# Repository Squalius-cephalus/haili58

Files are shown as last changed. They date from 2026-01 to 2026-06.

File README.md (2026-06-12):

# Haili58

Haili58 is a nrf52840 based 58-key column staggered split keyboard. PCB uses hotswap sockets. Design is inspired from REVIUNG41 and Corne keyboards.

PCB is designed for MX and Gateron low profile key switches. The keyboard is designed to be used with a USB dongle.

haili58 GLP and MX variant

## [Build Guide](https://github.com/Squalius-cephalus/haili58/wiki/Build-Guide)

## Firmware
Haili58 uses [ZMK firmware.](https://github.com/Squalius-cephalus/haili58_zmk)

TODO:
- RMK Firmware

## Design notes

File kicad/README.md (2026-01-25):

## Kicad Footprints

This project uses footprints from various repositories

 - [OLED Display 128x32](https://github.com/crides/kleeb/tree/master/display.pretty)
 - [Diode THT/SMD](https://github.com/foostan/kbd) 
 - [Power Switch MSK12C02](https://github.com/joe-scotto/scottokeebs/tree/main/Extras/ScottoKicad)
 - [nice!nano V2](https://github.com/joe-scotto/scottokeebs/tree/main/Extras/ScottoKicad)
 - [GLP Hotswap Socket](https://github.com/siderakb/key-switches.pretty)

Few of the footprints has been edited, those can be found in the **haili_project.pretty** directory.

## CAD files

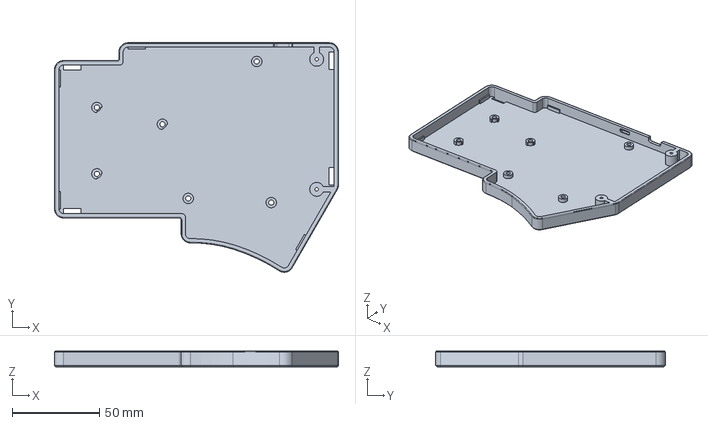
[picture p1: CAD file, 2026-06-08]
case/case_rev2/GLP/case.step
162.9 x 131.7 x 9.00 mm

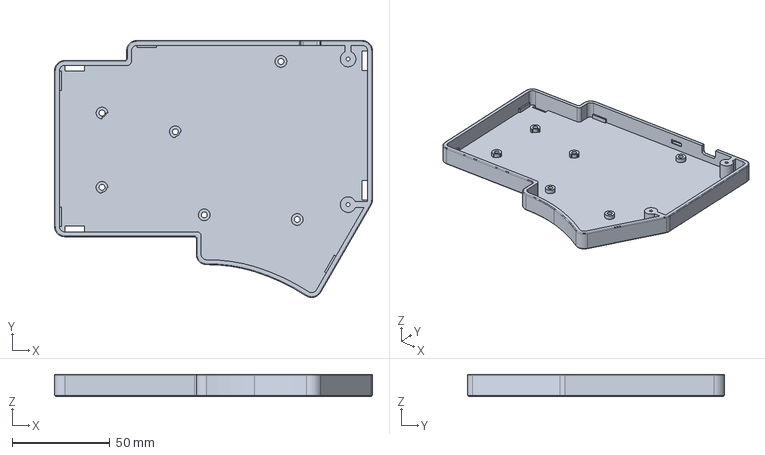
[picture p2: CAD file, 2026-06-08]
case/case_rev2/MX/case.step
162.9 x 131.7 x 11.5 mm

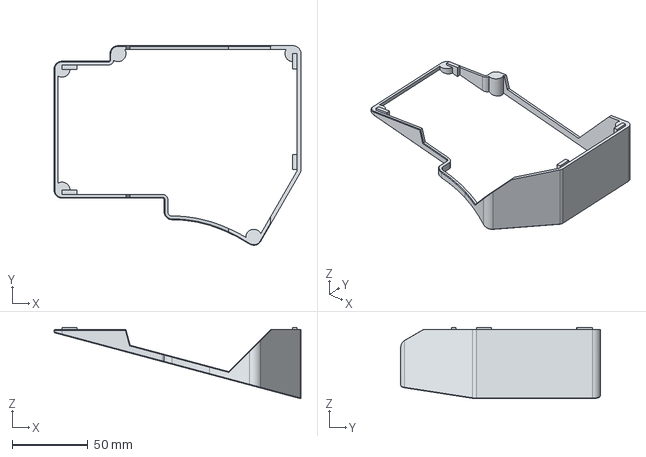
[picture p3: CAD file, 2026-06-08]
case/case_rev2/Tenting/15deg.step
162.9 x 131.7 x 47.0 mm

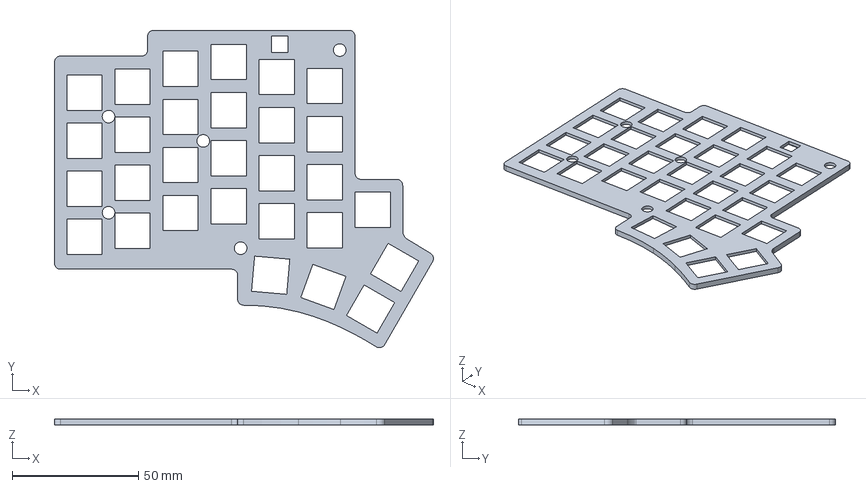
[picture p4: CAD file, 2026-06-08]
case/case_rev2/GLP/plate.step
150.3 x 125.9 x 2.50 mm

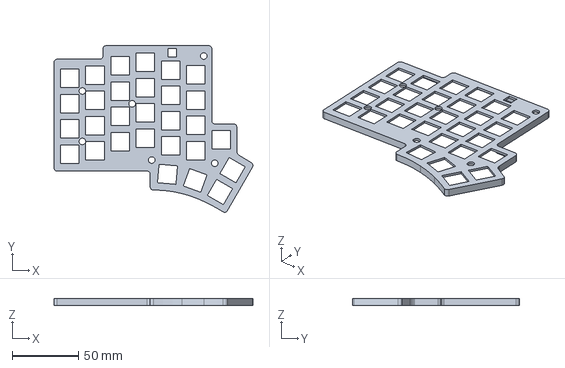
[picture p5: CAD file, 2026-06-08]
case/case_rev2/MX/plate.step
150.3 x 125.9 x 5.00 mm

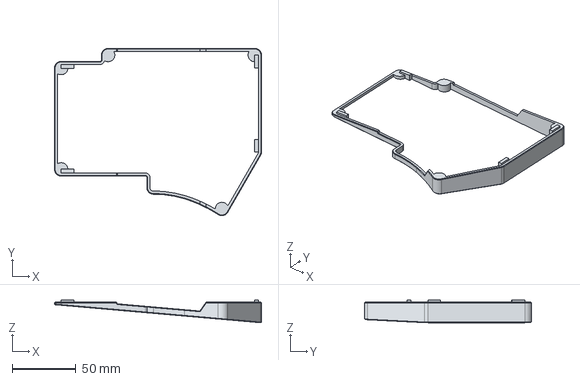
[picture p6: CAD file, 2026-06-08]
case/case_rev2/Tenting/5deg.step
162.9 x 131.7 x 17.7 mm

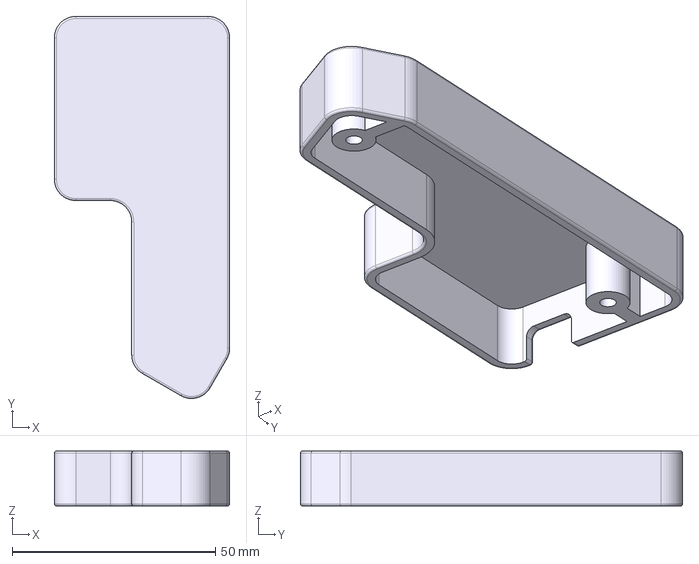
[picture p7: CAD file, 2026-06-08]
case/case_rev2/GLP/battery_cover.step
43.2 x 94.0 x 13.5 mm

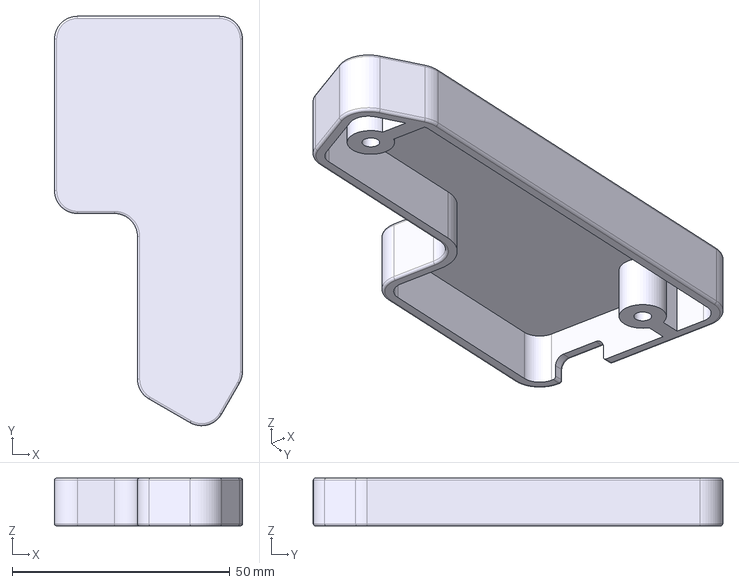
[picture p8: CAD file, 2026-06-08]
case/case_rev2/MX/battery_cover.step
43.2 x 94.0 x 11.0 mm

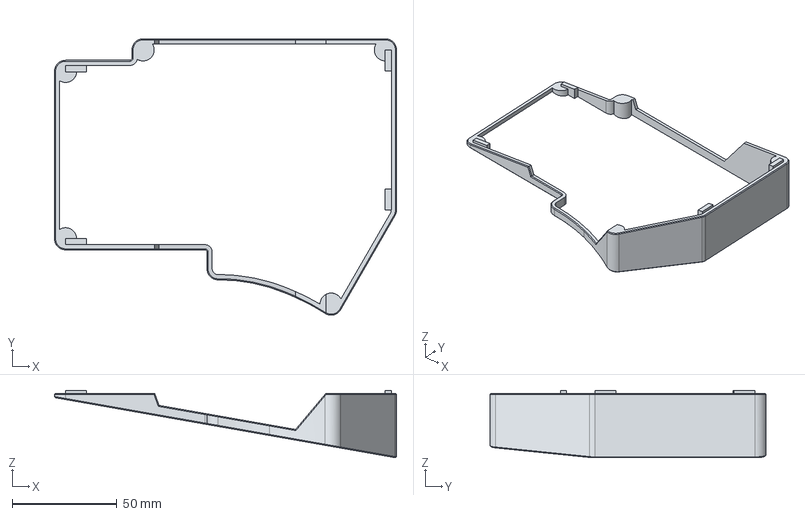
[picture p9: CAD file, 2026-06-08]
case/case_rev2/Tenting/10deg.step
162.9 x 131.7 x 32.1 mm

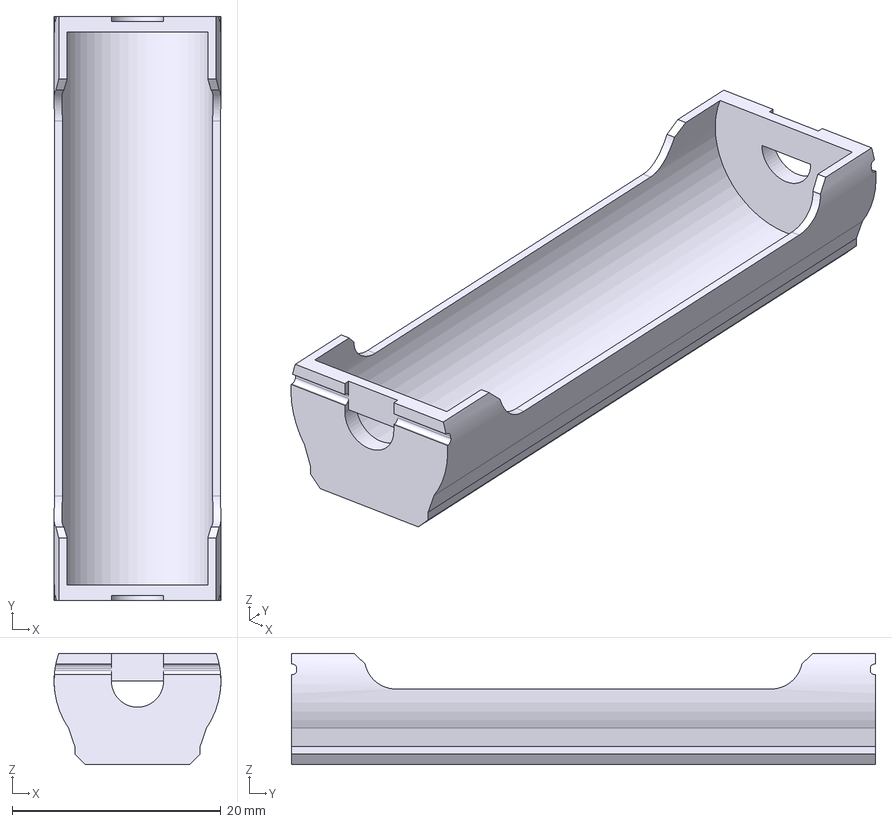
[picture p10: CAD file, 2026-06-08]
case/battery_holder/14500_holder.step
16.0 x 56.0 x 10.6 mm

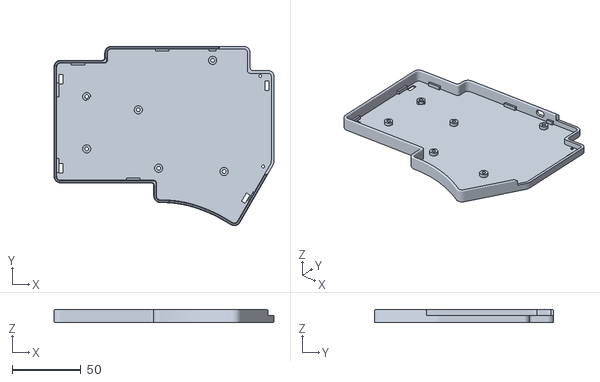
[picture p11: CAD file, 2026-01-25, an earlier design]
case/case_rev1/GLP/Body.stl
160.2 x 130.7 x 9.40

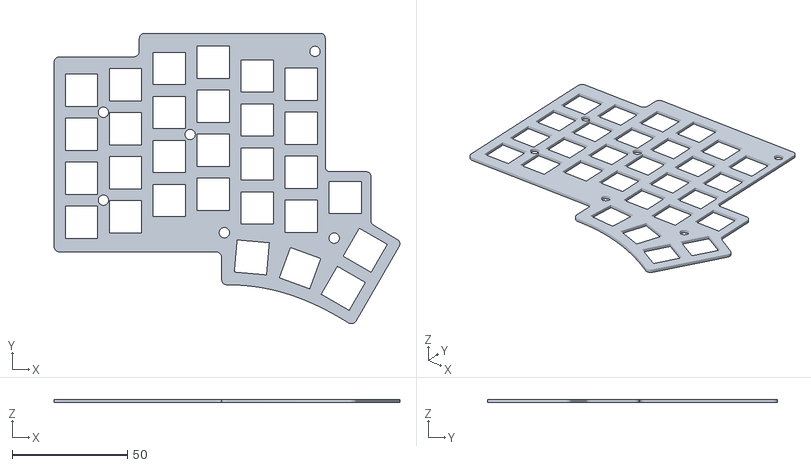
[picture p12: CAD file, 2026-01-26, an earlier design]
case/case_rev1/MX/Plate_without_reset.stl
149.9 x 125.9 x 1.50

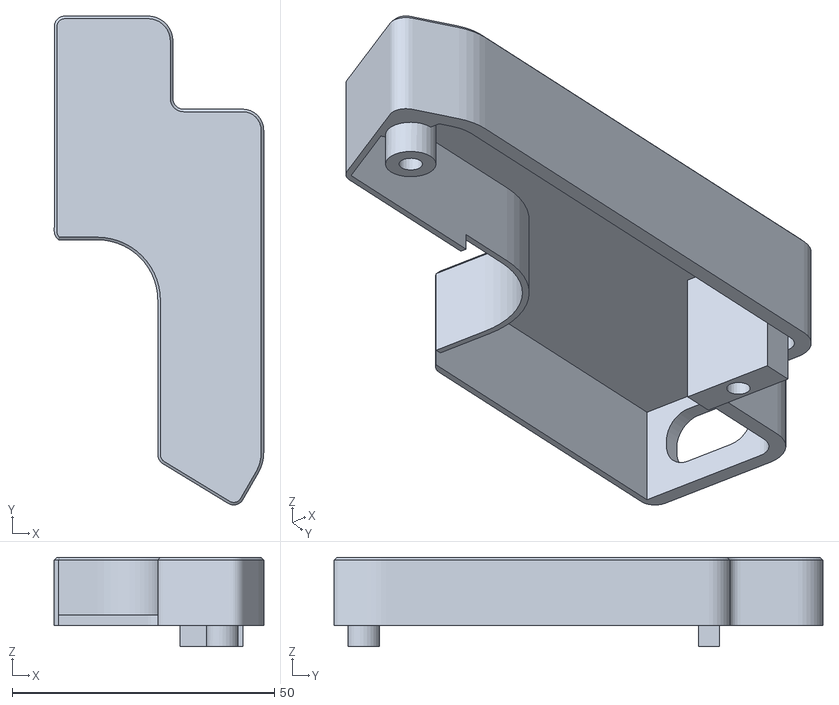
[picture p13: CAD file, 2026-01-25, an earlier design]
case/case_rev1/GLP/Cover.stl
39.9 x 93.2 x 17.0

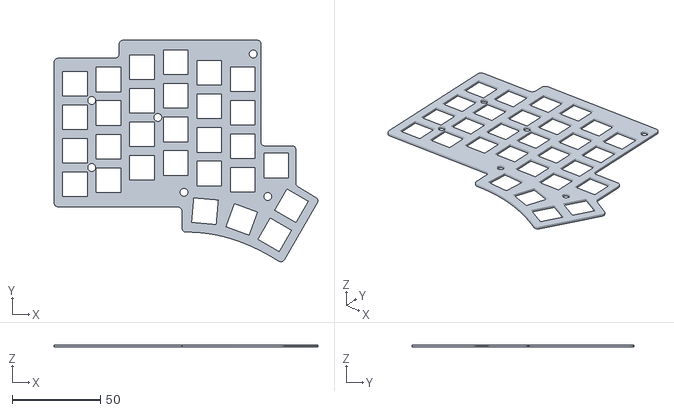
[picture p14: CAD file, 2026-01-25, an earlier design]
case/case_rev1/GLP/Plate_without_reset.stl
149.9 x 125.9 x 1.40

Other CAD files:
case/case_rev1/MX/Plate.stl
case/case_rev1/MX/Body.stl
case/case_rev1/GLP/Plate.stl

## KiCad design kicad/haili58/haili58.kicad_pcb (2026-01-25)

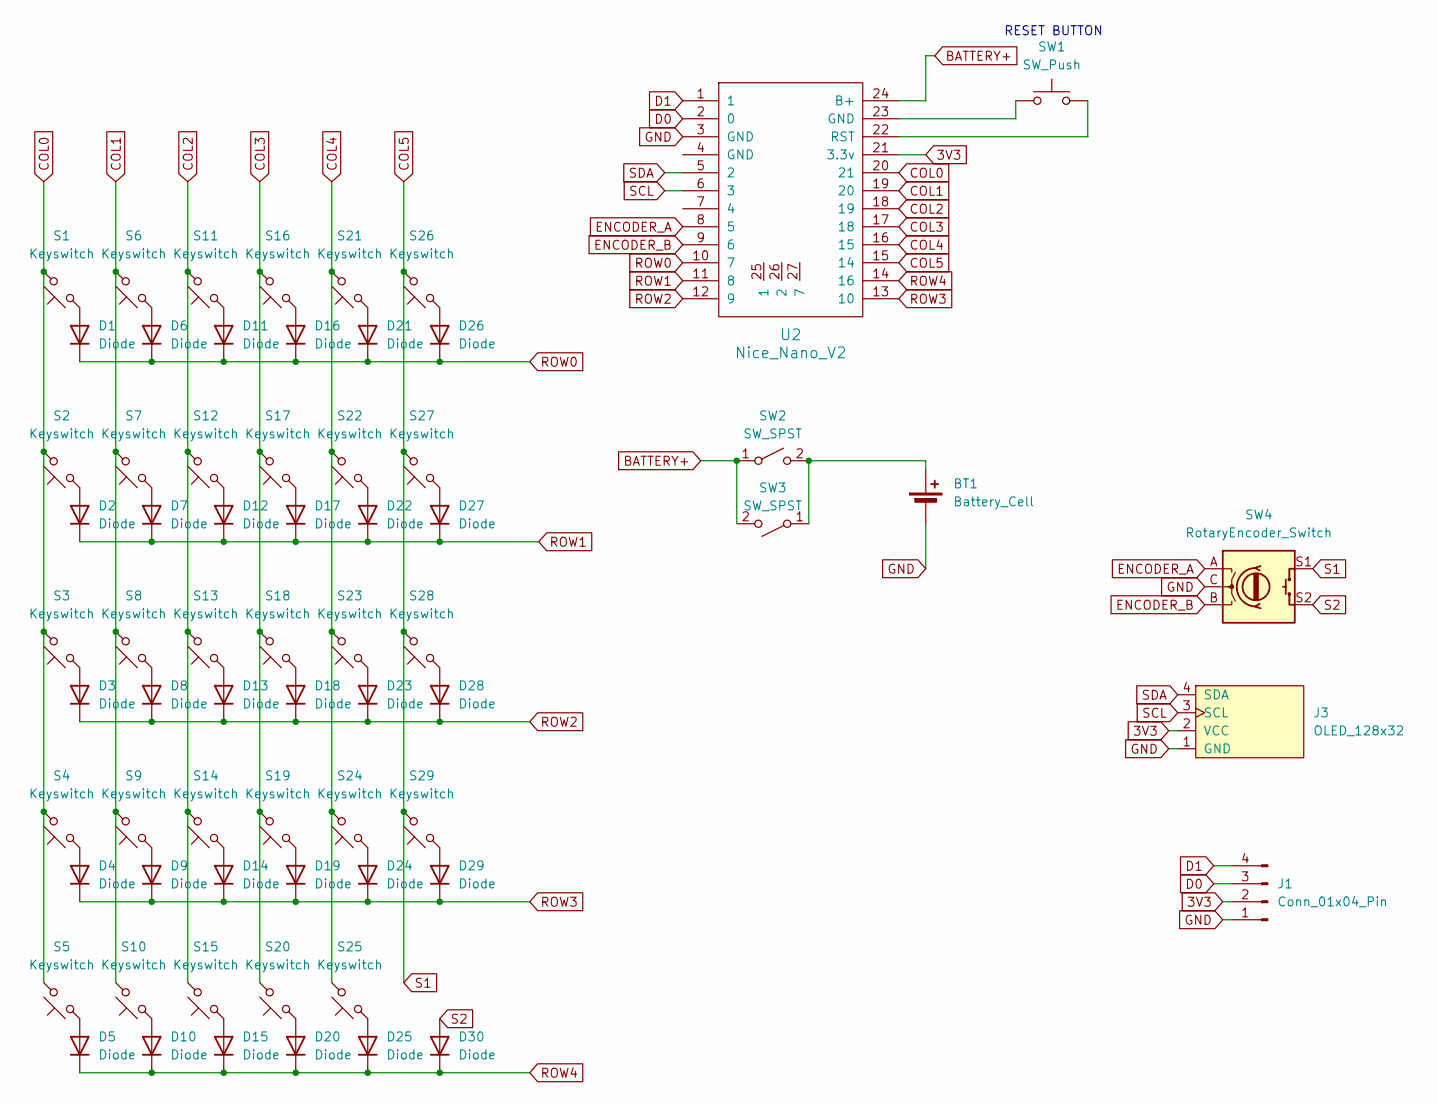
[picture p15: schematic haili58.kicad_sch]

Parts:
BT1: Battery_Cell; Battery_Pins_2mm
D1, D2, D3, D4, D5, D6, D7, D8, D9, D10, D11, D12, D13, D14, D15, D16, D17, D18, D19, D20, D21, D22, D23, D24, D25, D26, D27, D28, D29, D30: Diode; D3_TH_SMD_v2
J1: Conn_01x04_Pin; PinSocket_1x04_P2.54mm_Vertical
J3: OLED_128x32; OLED-128x32-double-sided
S1, S2, S3, S4, S5, S6, S7, S8, S9, S10, S11, S12, S13, S14, S15, S16, S17, S18, S19, S20, S21, S22, S23, S24, S25, S26, S27, S28, S29: Keyswitch; SW_Gateron_LowProfile_HotSwap_PTH_edited
SW1: SW_Push; SW_PUSH_6mm_H4.3mm
SW2, SW3: SW_SPST; Switch_MSK12C02
SW4: RotaryEncoder_Switch; RotaryEncoder_Alps_EC11E-Switch_Vertical_H20mm
U2: Nice_Nano_V2; Nice_Nano_V2_edited

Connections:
3V3: J1.2, J3.2 (VCC), U2.21 (3.3v)
BATTERY+: SW2.1 (A), SW3.2 (B), U2.24 (B+)
COL0: S1.2, S2.2, S3.2, S4.2, S5.2, U2.20 (21)
COL1: S6.2, S7.2, S8.2, S9.2, S10.2, U2.19 (20)
COL2: S11.2, S12.2, S13.2, S14.2, S15.2, U2.18 (19)
COL3: S16.2, S17.2, S18.2, S19.2, S20.2, U2.17 (18)
COL4: S21.2, S22.2, S23.2, S24.2, S25.2, U2.16 (15)
COL5: S26.2, S27.2, S28.2, S29.2, SW4.S1, U2.15 (14)
D0: J1.3, U2.2 (0)
D1: J1.4, U2.1
ENCODER_A: SW4.A, U2.8 (5)
ENCODER_B: SW4.B, U2.9 (6)
GND: BT1.2 (-), J1.1, J3.1 (GND), SW4.C, U2.3 (GND)
unnamed: BT1.1 (+), SW2.2 (B), SW3.1 (A)
unnamed: D1.2 (A), S1.1
unnamed: D2.2 (A), S2.1
unnamed: D3.2 (A), S3.1
unnamed: D4.2 (A), S4.1
unnamed: D5.2 (A), S5.1
unnamed: D6.2 (A), S6.1
unnamed: D7.2 (A), S7.1
unnamed: D8.2 (A), S8.1
unnamed: D9.2 (A), S9.1
unnamed: D10.2 (A), S10.1
unnamed: D11.2 (A), S11.1
unnamed: D12.2 (A), S12.1
unnamed: D13.2 (A), S13.1
unnamed: D14.2 (A), S14.1
unnamed: D15.2 (A), S15.1
unnamed: D16.2 (A), S16.1
unnamed: D17.2 (A), S17.1
unnamed: D18.2 (A), S18.1
unnamed: D19.2 (A), S19.1
unnamed: D20.2 (A), S20.1
unnamed: D21.2 (A), S21.1
unnamed: D22.2 (A), S22.1
unnamed: D23.2 (A), S23.1
unnamed: D24.2 (A), S24.1
unnamed: D25.2 (A), S25.1
unnamed: D26.2 (A), S26.1
unnamed: D27.2 (A), S27.1
unnamed: D28.2 (A), S28.1
unnamed: D29.2 (A), S29.1
unnamed: SW1.1, U2.23 (GND)
unnamed: SW1.2, U2.22 (RST)
ROW0: D1.1 (K), D6.1 (K), D11.1 (K), D16.1 (K), D21.1 (K), D26.1 (K), U2.10 (7)
ROW1: D2.1 (K), D7.1 (K), D12.1 (K), D17.1 (K), D22.1 (K), D27.1 (K), U2.11 (8)
ROW2: D3.1 (K), D8.1 (K), D13.1 (K), D18.1 (K), D23.1 (K), D28.1 (K), U2.12 (9)
ROW3: D4.1 (K), D9.1 (K), D14.1 (K), D19.1 (K), D24.1 (K), D29.1 (K), U2.13 (10)
ROW4: D5.1 (K), D10.1 (K), D15.1 (K), D20.1 (K), D25.1 (K), D30.1 (K), U2.14 (16)
S2: D30.2 (A), SW4.S2
SCL: J3.3 (SCL), U2.6 (3)
SDA: J3.4 (SDA), U2.5 (2)

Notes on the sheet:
RESET BUTTON

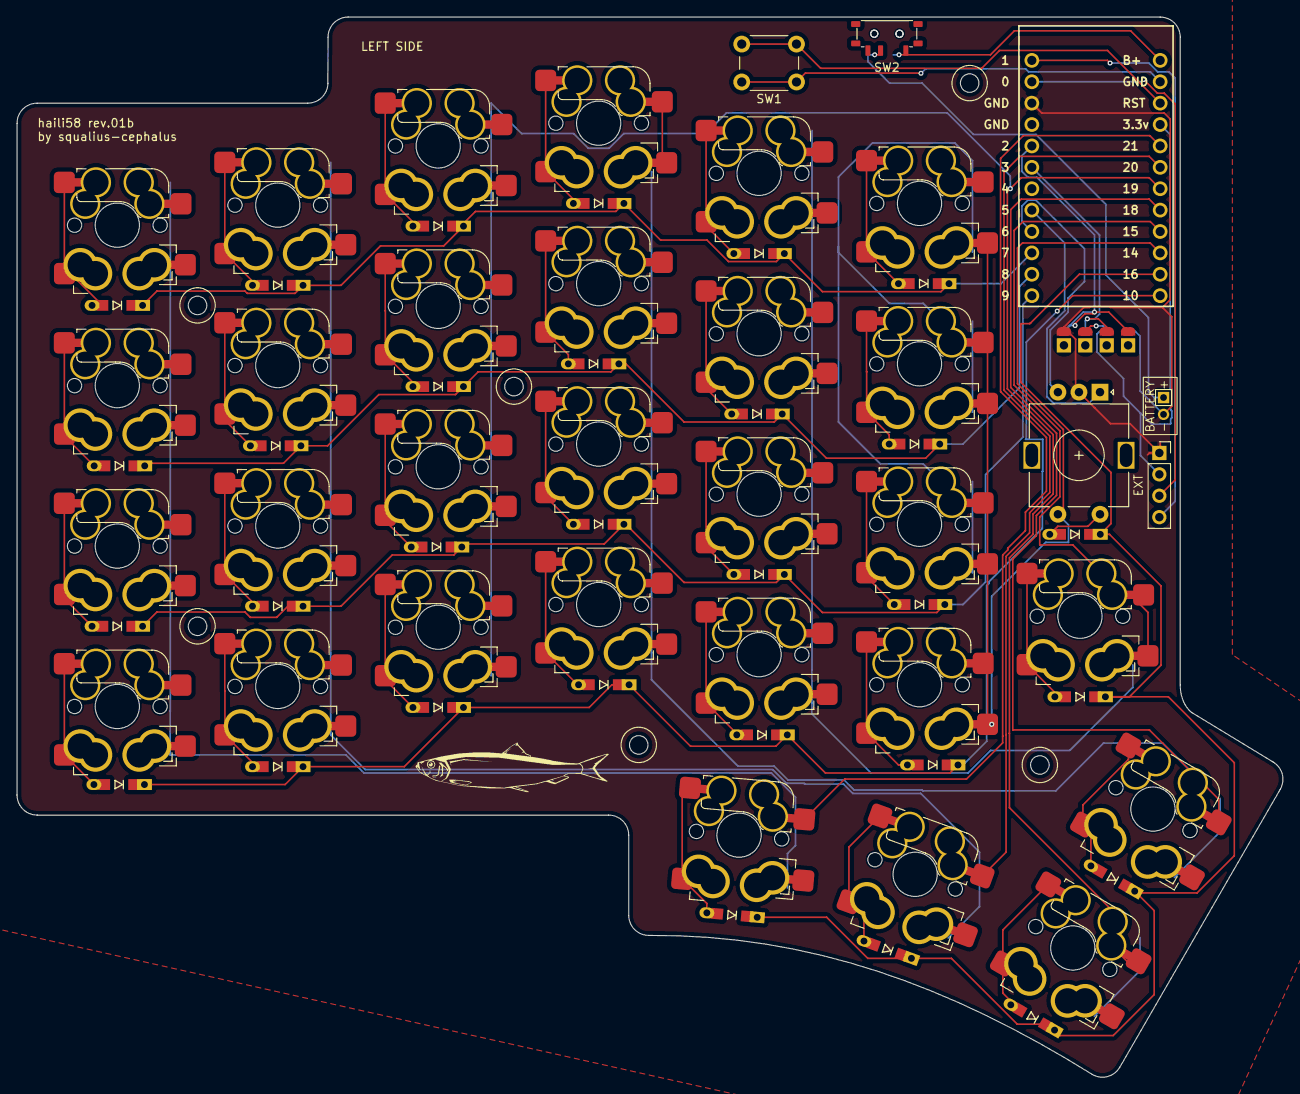
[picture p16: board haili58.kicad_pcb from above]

Board: 2 copper layers, 150.3 x 125.9 mm, 67 parts (1 on the bottom side), 53 nets.

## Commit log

2026-01-25 STL files, Kicad files etc
    [Body.stl, Cover.stl, Plate.stl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]
2026-01-25 Update and rename FOOTPRINTS.MD to FOOTPRINTS
2026-01-26 Added MX compatible parts
    [Body.stl, Cover.stl, Plate.stl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]
2026-06-08 New case, new README.
    [10deg.step, 14500_holder.step, 15deg.step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]
